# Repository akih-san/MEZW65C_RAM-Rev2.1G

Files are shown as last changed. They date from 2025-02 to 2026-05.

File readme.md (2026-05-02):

# MEZW65C_RAM-Rev2.1G

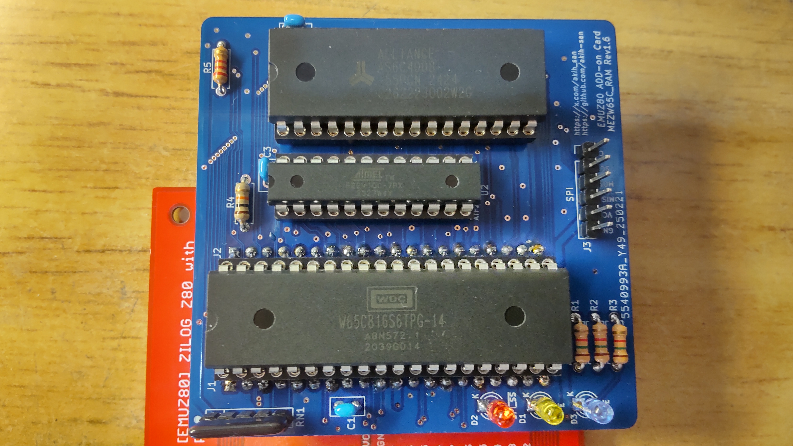
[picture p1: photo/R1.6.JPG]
<br>
（MEZW65C_RAM Rev1.6メザニンボード）
<br>

## MEZW65C_RAM-Rev2.1（PCB Rev1.3)からの改良点<br>
<br>
１．CPUの高速化<br>
２．CPLD(GAL)導入によるPCBの部品点数を削減<br>
３．ファームウェアによる6502、65816の自動判定<br>

#### １．CPUの高速化(6502:10MHz, 65816:8Mhz)
Rev2.1(PCB Rev1.3)は、6502(8MHz)、65816(6MHz)で動作しています。<br>
しかし、W65C02S6TPG-14とW65C816S6TPG-14を定格のは14MHzです。<br>
使用しているSRAM(AS6C4008-55PCN)のアクセスタイムは55nsですから、<br>
もう少し早く動かすことが出来るはずです。<br>
色々調べた結果、少し回路を修正すれば出来そうです。<br>
その為には、標準ロジックICを追加する必要がありますが、<br>
PCB Rev1.3には面積的にICを追加することは不可能な状況でした。<br>
<br>
今回、CPLDを導入し、部品点数を減らしたPCBを作成することで、<br>
6502で10MHz、65816では8MHzで動作することが出来るようになります。<br>
<br>
（65816について補足）<br>
65816は、クロックの半周期（CLKの立ち上がり）でメモリアドレス確定し、<br>
残りの半周期（CLKの立下り）でデータを確定する仕様です。<br>
またデータ確定時（CLKの立ち下がり）のsetup timeが最低10ns必要となります。<br>
このため、アクセスタイム55nsのSRAM(AS6C4008-55PCN)では、55ns+10ns=65nsが<br>
データ確定までに必要な時間となります。<br>
このため、動作クロックの論理値は、f=1/(65ns*2)となり、[約7.69MHz](photo/w65c816%20timing%20chart.png)となります。<br>
8MHzは実力で動作しているようなので、設定ファイル（MEZW16.CFG）には8MHzで動作するように<br>
設定してあります。<br>
メモリ、CPUの個体差で動作しない場合、クロックを7MHzに下げてください。<br>
<br>
<br>
＜余談＞<br>
14MHzで動かすには、もっと高速なSRAMが必要です。<br>
X(旧Twitter)の@DragonBallEZさんが、MH678127UHJ-12の高速SRAMを<br>
AS6C1008のピン配置に変換するアダプタ「Little Demon1 Rev0.3」を<br>

を作成しているので、 それを使って実験したところ、[14MHzで動作](photo/opening14MHz.png)することが<br>
確認出来ました。[ASCIIARTの結果](photo/asciiart.png)<br>
（MH678127UHJ-12は秋月電子通商での販売が終了しており、入手困難です）<br>

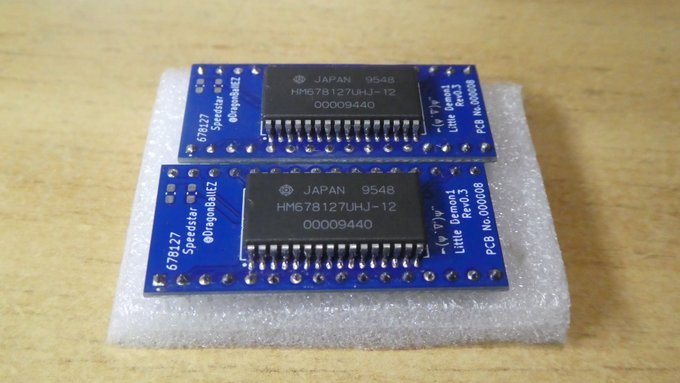
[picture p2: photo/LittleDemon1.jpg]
<br>
（Little Demon1 Rev0.3）
<br>

#### ２．CPLD(GAL)導入によるPCBの部品点数を削減
Glue logicは、CPLDを使えば複数の標準ロジックICを、規模にもよりますが<br>
１つにまとめることが可能です。<br>
PCB Rev1.3には３つの標準ロジックICがあります。追加のGlue logicと<br>
３つの標準ロジックICを、１つの22V10タイプのCPLDにまとめることが出来ました。<br>
CPLDは、私自信にとって初めての挑戦でしたが、うまくいきました。<br>

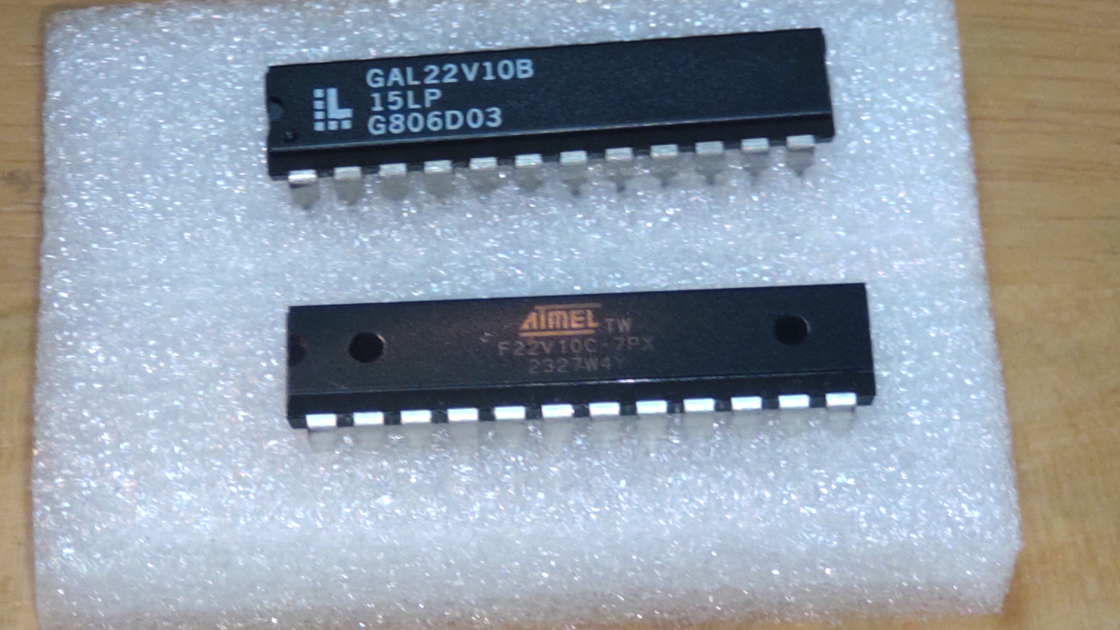
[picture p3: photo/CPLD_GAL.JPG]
<br>
（今回使用したCPLDとGAL）
<br>

#### ３．ファームウェアによる6502、65816の自動判定<br>
Rev2.1(PCB Rev1.3)は、切替スイッチを使って手動でCPUの種類を切り替えていました。<br>
Rev1.2G(PCB Rev1.6)では、ファームウェアによってCPUを自動判定します。<br>
その為、切り替えスイッチが無くなっています。<br>
<br>
CPLDの導入と、ファームウェアによるCPUの自動判定により、PCBの部品点数が削減されて<br>
スッキリとなりました。<br>
CPUの抜き差しをしやすいように、LEDの配置を変更しています。<br>
部品点数が減ったため、SRAMやPLDの抜き差しも楽になりました。<br>

# CPLDへのプログラミングと書き込み
CPLDの開発環境は、マイクロチップ社がPLD Design Resourcesとして[WinCUPL](https://www.microchip.com/en-us/products/fpgas-and-plds/spld-cplds/pld-design-resources)を提供しています。<br>
プログラミング自体は、慣れたテキストエディタを使えます。コンパイルとコード生成（jedファイル）<br>
をWinCUPLで行います。<br>
WinCUPLは少し古いソフトですが、Windows11でも動作しています。ただし、インストールすると<br>
既存の環境変数を書き換えてしまうので、既存の環境変数をバックアップしておく必要があります。<br>
そうしないと、既存のソフトウェアが立ち上がらなくなったりする不具合が発生するので、<br>
注意が必要です。<br>
CPLDのプログラミングについては[ここ](https://satoru8765.hatenablog.com/entry/2024/09/16/174243)が参考になると思います。<br>
<br>
 - CPLDへの書き込み<br>

   CPLDには、ROMライタを使用してMEZW65C_RAM.jedファイルを書込みます。<br>
   使用したのは、XGecu Programmer Model TL866Ⅱ PLUSです。<br>
   少し古いですが、問題なく書き込みが出来ました。XGecu Official Siteは[こちら](https://xgecu.myshopify.com/)<br>

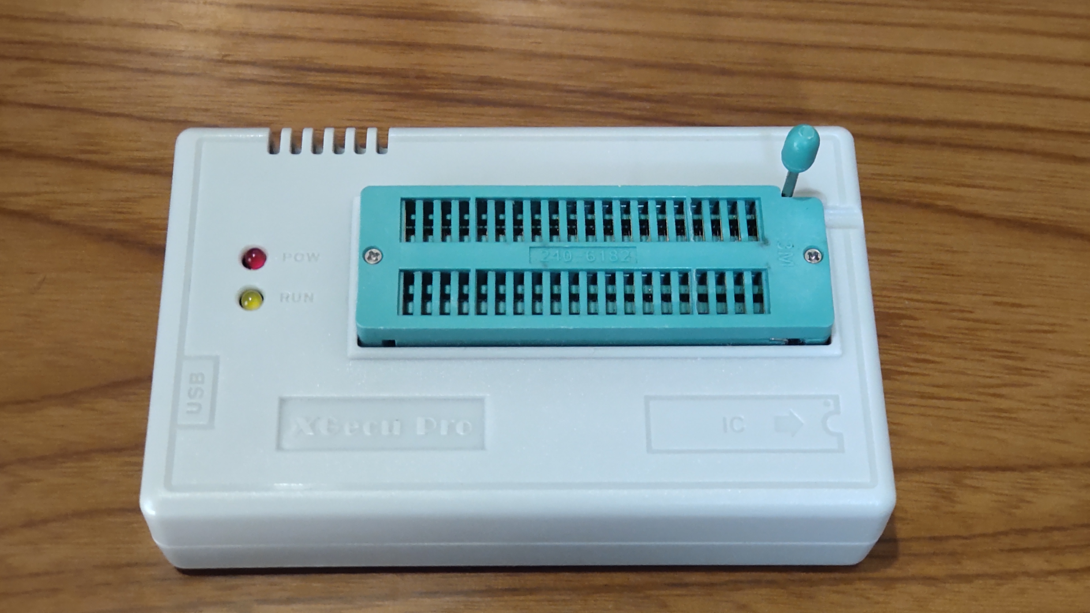
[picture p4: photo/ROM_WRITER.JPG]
   <br>
（今回使用したROMライタ）

# PIC18F47Q43/Q84/Q83への書き込み
PICへの書き込みツールを用いて、ヘキサファイルを書き込みます。<br>
<br>
- PIC18F47Q43 - R2.1GQ43.hex
- PIC18F47Q84 - R2.1GQ84.hex
- PIC18F47Q83 - R2.1GQ83.hex
<br>
＜注意点＞<br>
EMUZ80ボードから、メザニンボード（MEZW65C_RAM Rev2.1G）を外した状態で<br>
PICへの書き込みを行います。メザニンボードを装着しての書き込みは、失敗が<br>
多いです。<br>
もしくは、PICに書き込めるライターを使用します。<br>
<br>
- snap(マイクロチップ社の書き込みツール)<br>

  - [snap](https://www.microchip.com/en-us/development-tool/PG164100)

<br>
- PICkit3（または互換ツール）<br><br>
  PICkitminus書き込みソフトを用いて、書き込むことが出来ます。以下で入手できます。<br>

  - [PICkitminus](http://kair.us/projects/pickitminus/)
<br>

# μSDカードの作成
[MEZW65C_RAM Rev2.1のDISKSディレクトリの中身全部](https://github.com/akih-san/MEZW65C_RAM-Rev2.1/tree/main/DISKS)のファイルをμSDカードにコピーします。<br>
6502/65816を10MHzで動かすため、[コンフィグファイル](DISKS)を上書きします。<br>
<br>

# その他
詳細については、<br>
  - [MEZW65C_RAM Rev2.0](https://github.com/akih-san/MEZW65C_RAM-Rev2.0)<br>
  - [MEZW65C_RAM Rev2.1](https://github.com/akih-san/MEZW65C_RAM-Rev2.1)<br>
<br>
を参照してください。<br>

# 参考

＜EMUZ80＞<br>
EUMZ80はZ80CPUとPIC18F47Q43のDIP40ピンIC2つで構成されるシンプルなコンピュータです。<br>
（電脳伝説 - EMUZ80が完成）  <br>
https://vintagechips.wordpress.com/2022/03/05/emuz80_reference  <br>
<br>
＜SuperMEZ80＞<br>
SuperMEZ80は、EMUZ80にSRAMを追加しZ80をノーウェイトで動かすことができます。<br>
https://github.com/satoshiokue/SuperMEZ80<br>
<br>
＜＠hanyazouさんのソース＞<br>
https://github.com/hanyazou/SuperMEZ80/tree/mez80ram-cpm<br>
<br>
＜@electrelicさんのユニバーサルモニタ＞<br>
https://electrelic.com/electrelic/node/1317<br>

＜オレンジピコショップ＞  <br>
オレンジピコさんでEMUZ80、その他メザニンボードの購入できます。<br>
<br>
https://store.shopping.yahoo.co.jp/orangepicoshop/pico-a-051.html<br>
https://store.shopping.yahoo.co.jp/orangepicoshop/pico-a-061.html<br>
https://store.shopping.yahoo.co.jp/orangepicoshop/pico-a-062.html<br>
https://store.shopping.yahoo.co.jp/orangepicoshop/pico-a-079.html<br>
https://store.shopping.yahoo.co.jp/orangepicoshop/pico-a-087.html<br>
https://store.shopping.yahoo.co.jp/orangepicoshop/pico-a-089.html<br>

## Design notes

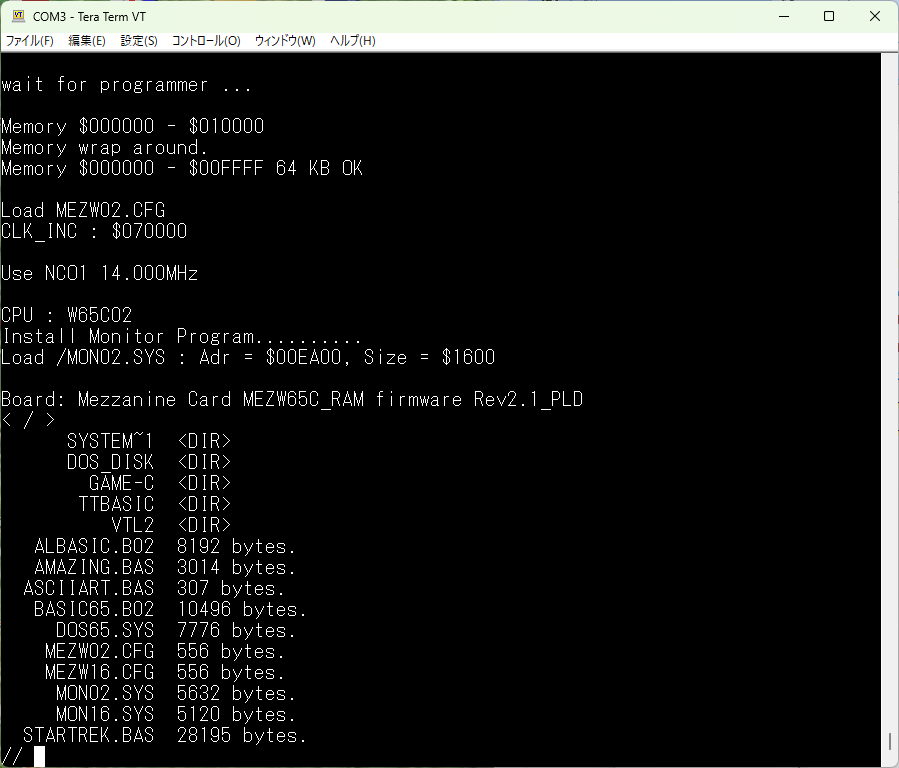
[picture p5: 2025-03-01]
photo/opening14MHz.png

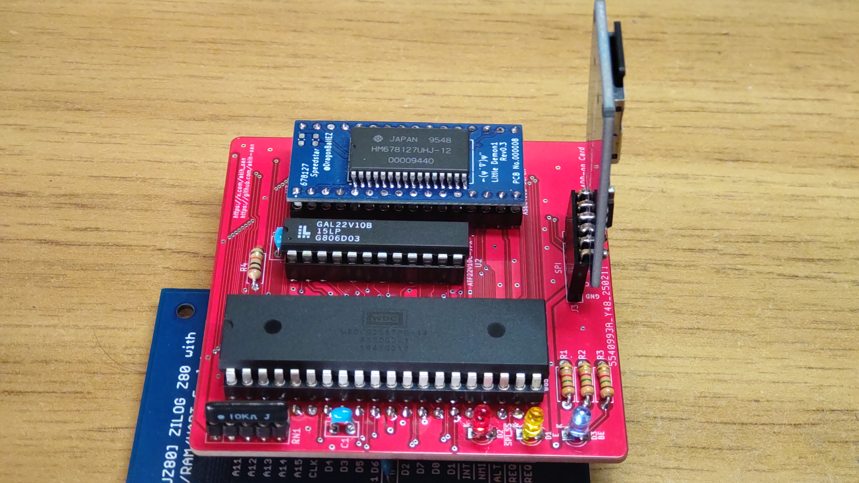
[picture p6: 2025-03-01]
photo/R1.5_14MHz.JPG

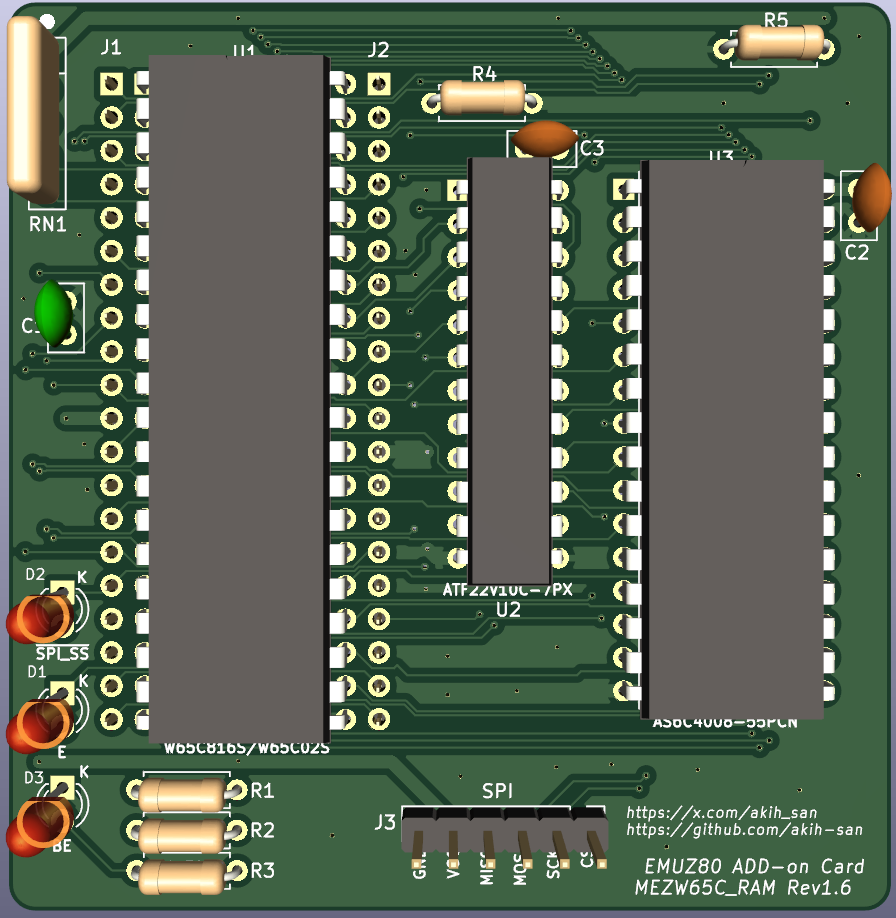
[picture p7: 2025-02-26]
photo/MEZ65C_RAM Rev1.6_1.png

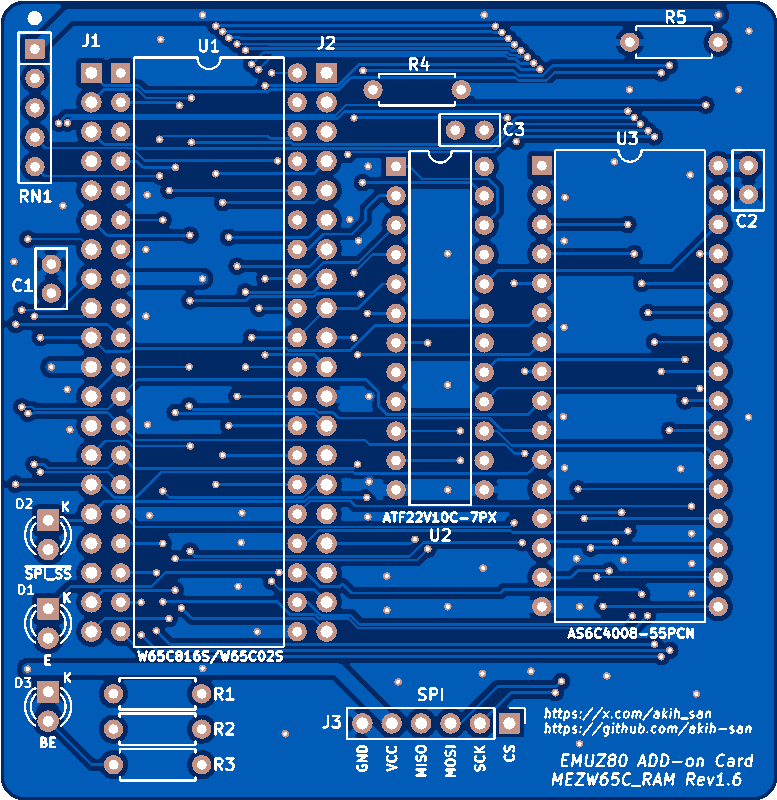
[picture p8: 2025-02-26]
photo/MEZ65C_RAM Rev1.6_2.png

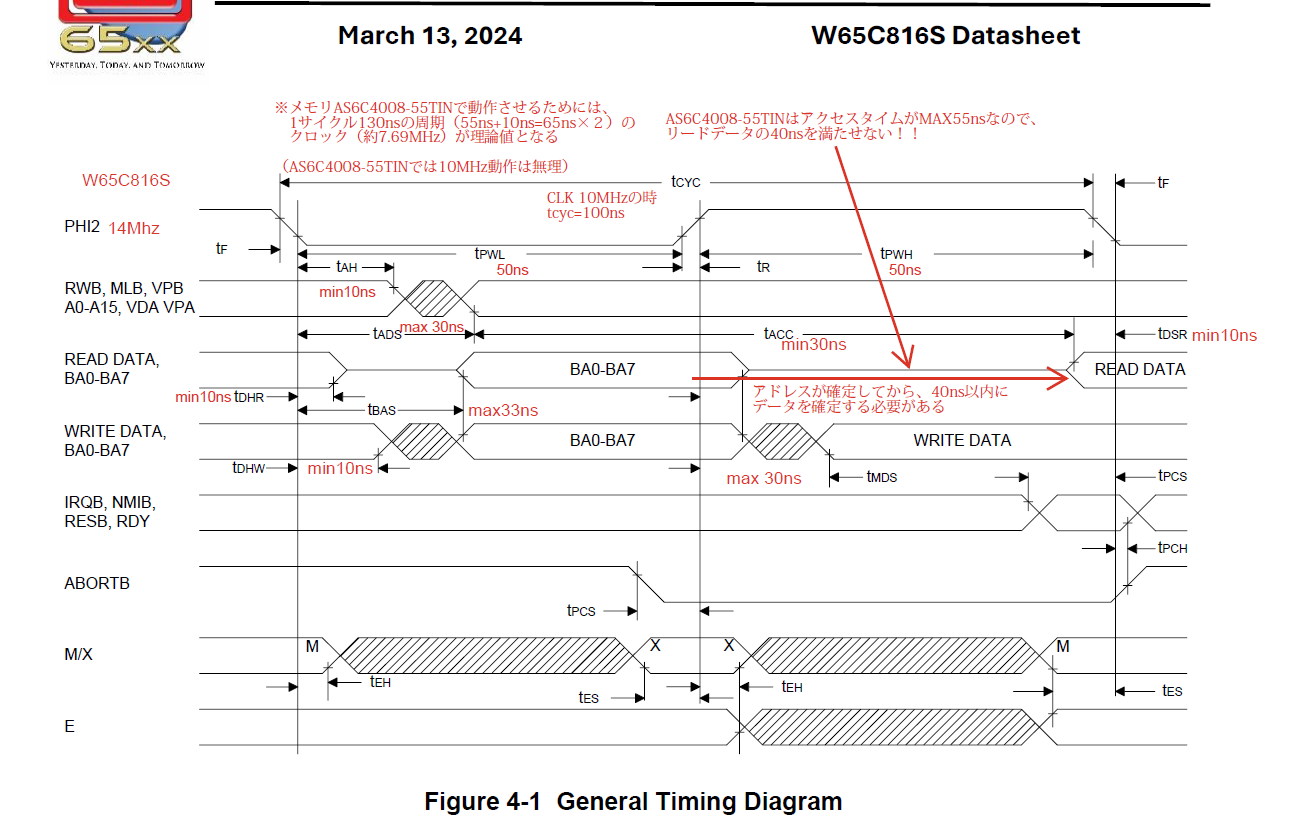
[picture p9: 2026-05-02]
photo/w65c816 timing chart.png

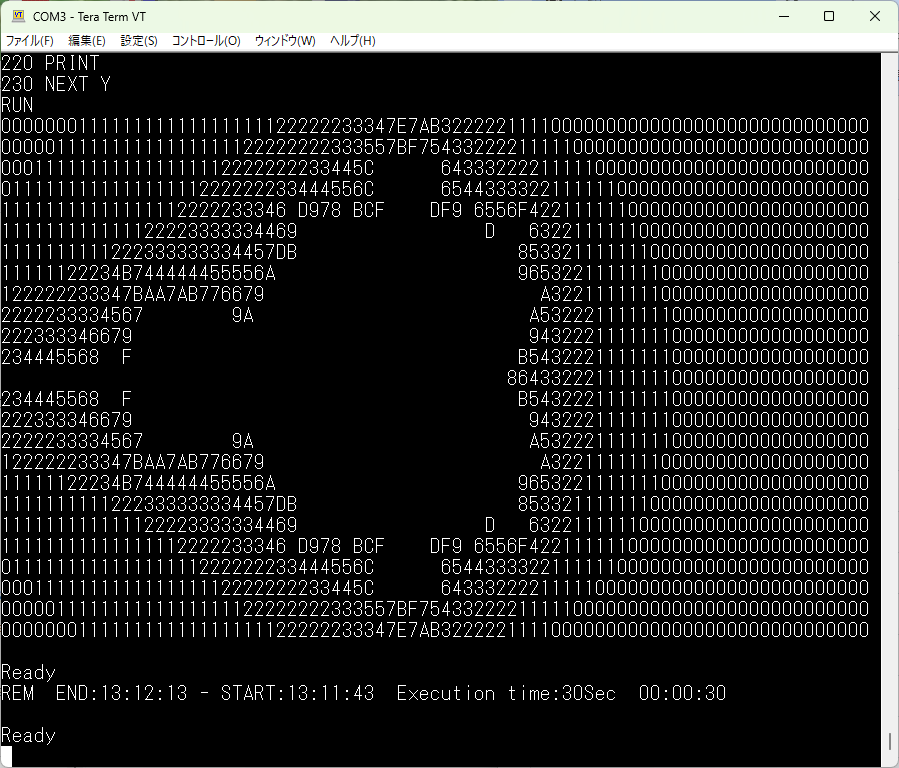
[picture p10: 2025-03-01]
photo/asciiart.png

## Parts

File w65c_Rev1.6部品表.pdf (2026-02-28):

＜w65c_Rev1.6 列 1 | | 列 2 | 列 3 | 列 4
No. | 部品番号 | 数 | 値、品番 | 名称

1

2 | D1,D2,D3 | 3 | LED | 発光ダイオード　順電圧 2 - 2.2V
3 | J1,J2 | 2 | 20ピンソケット | EMUZ80接続用2.54mmピッチ
4 | J3 | 1 | SPI | μSDカード用 1x06 2.54mmピッチピンヘッダ
5 | R1,R2,R3 | 3 | 1.5KΩ 1/4W | カーボン抵抗(炭素皮膜抵抗)
6 | R4 | 1 | 10KΩ 1/4W | カーボン抵抗(炭素皮膜抵抗)
7 | R5 | 1 | 2.2KΩ 1/4W | カーボン抵抗(炭素皮膜抵抗)
8 | RN1 | 1 | 4素子 10kΩ | 集合抵抗 4素子
9 | U1 | 1 | CPU | CPU W65C816S / W65C02 （DIP40）
10 | U2 | 1 | CPLD(GAL | ATF22V10C-7PXまたは、GAL22V10B-15LP
11 | U3 | 1 | AS6C4008-55PCN | 512kw×8bit SRAM（DIP32)
C1,C2,C3 | 3 | 0.1μF | 積層セラミックコンデンサー　D5.0mm W2.5mm P2.50mm

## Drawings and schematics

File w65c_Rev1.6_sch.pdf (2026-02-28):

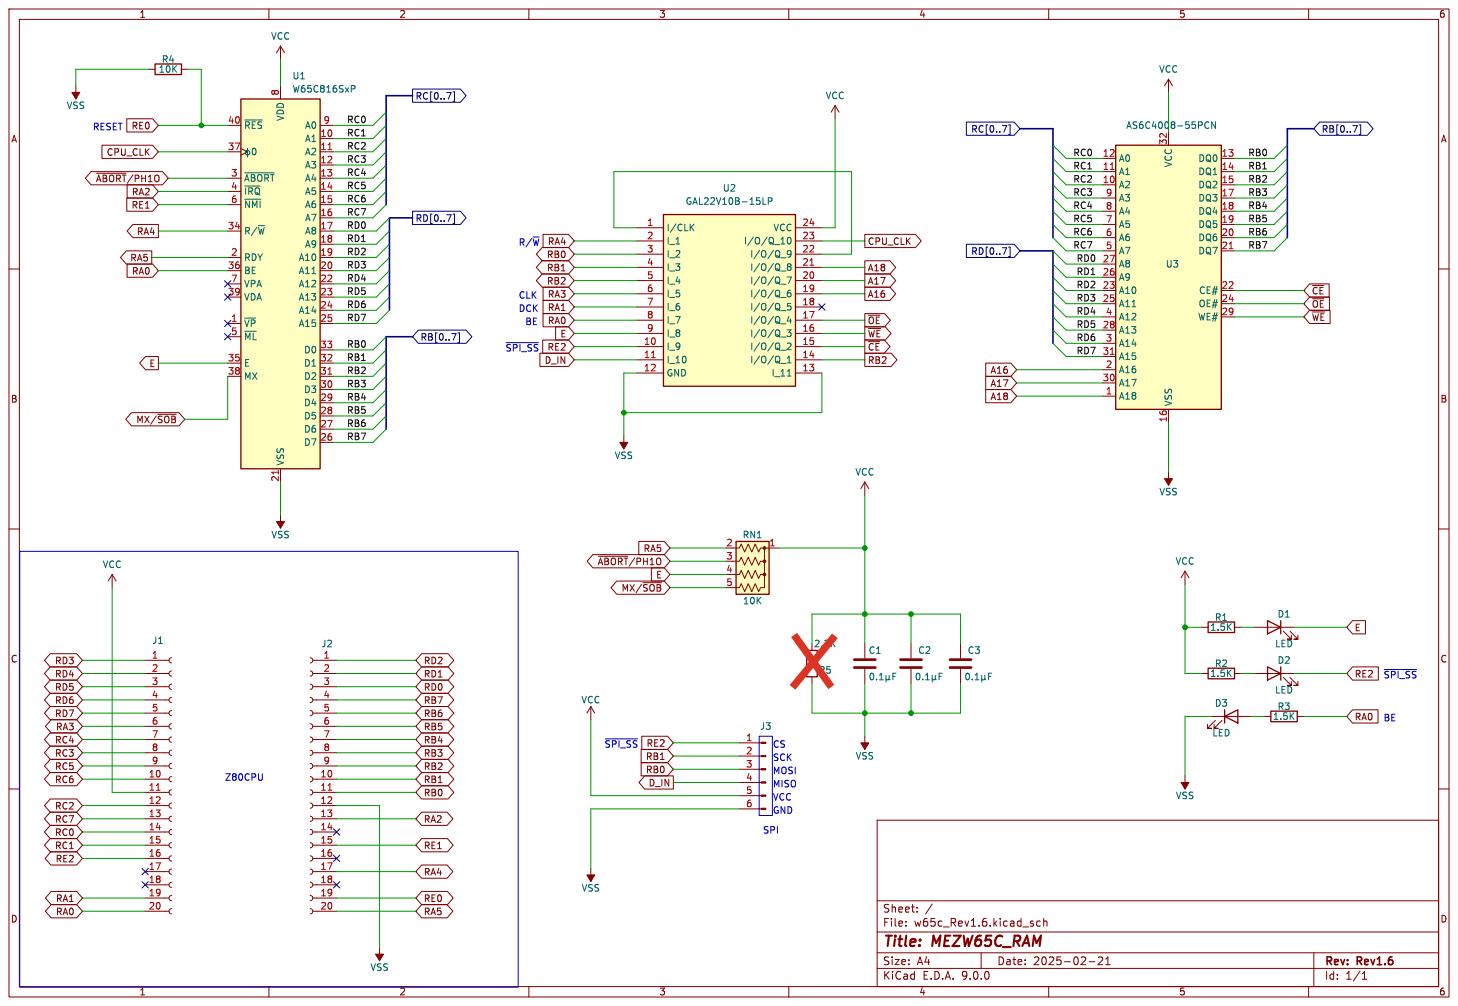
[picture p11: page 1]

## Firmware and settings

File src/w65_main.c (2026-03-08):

/*
 * Based on main.c by Tetsuya Suzuki 
 * and emuz80_z80ram.c by Satoshi Okue
 * PIC18F47Q43/PIC18F47Q83/PIC18F47Q84 ROM image uploader
 * and UART emulation firmware.
 * This single source file contains all code.
 *
 * Base source code of this firmware is maked by
 * @hanyazou (https://twitter.com/hanyazou) *
 *
 *  Target: MEZW65C02_RAM
 *  Written by Akihito Honda (Aki.h @akih_san)
 *  https://x.com/akih_san
 *  https://github.com/akih-san
 *
 *  Date. 2024.8.30
 */

#define INCLUDE_PIC_PRAGMA
#include <stdio.h>
#include <stdlib.h>
#include <string.h>
#include <ctype.h>

#include "../src/w65.h"
#include "../drivers/utils.h"

/* Previous function declaration */
static int disk_init(void);
static int load_program(uint8_t * );
static uint8_t del_space(char *);
static int load_config(void);
static int get_line(char *, int);

static FRESULT scan_files(void);
static FRESULT scan_files1(void);
static FRESULT change_directory(void);
static FRESULT load_file(void);
static FRESULT mon_prog(void);
static FRESULT wstart_prog(void);
static FRESULT restart_prog(void);
static FRESULT return_cpu(void);
static FRESULT print_reg(void);
static FRESULT print_com(void);
static FRESULT boot_file(void);
static FRESULT mem_dump(void);
static FRESULT drive_cpu(void);
static FRESULT see_file(void);
static FRESULT flash_apl(void);
static FRESULT open_dos65(void);
static FRESULT close_dos65(void);

static void set_arg(char *);
static int setup_monitor(void);
static int in_file(void);
static unsigned int str_inf(char *, uint8_t);

#define BS	0x08
#define CR	0x0d
#define BUF_SIZE TMP_BUF_SIZE * 2

#define INPUT_UART	0
#define INPUT_FILE	1

debug_t debug = {
    0,  // disk
    0,  // disk_read
    0,  // disk_write
    0,  // disk_verbose
    0,  // disk_mask
};

/* define structure type */
typedef struct {
	const TCHAR *conf;
	uint32_t *val;
} sys_param;

typedef struct {
	char *cmd_name;
	FRESULT (*func)(void);
} com_param;

static const char *mezID = "MEZW65C";
static char *board_name = "Mezzanine Card MEZW65C_RAM firmware Rev2.1_PLD";
static const TCHAR *conf02 = "MEZW02.CFG";
static const TCHAR *conf16 = "MEZW16.CFG";
static char *mon02 = "/MON02.SYS";
static char *mon16 = "/MON16.SYS";

static char *dosdir	= "DOS_DISK";
static char *dos65 = "/DOS65.SYS";

/* global values */
drive_t drives[NUM_DRIVES];

file_header fh;

uint8_t tmp_buf[2][TMP_BUF_SIZE];

int (*get_char[2])(void) = {
	u_getch,
	in_file
};

unsigned int (*strin_func[2])(char *, uint8_t) = {
	get_str,
	str_inf
};

uint8_t cin_no;			// 0 : INPUT_UART 1 : INPUT_FILE

uint32_t clk_fs;
uint32_t bioreq_ubuffadr;
uint32_t bioreq_cbuffadr;

// CPU flg 0:W65C02 1:W65C816
uint8_t	cpu_flg;
uint8_t	wup_flg;
uint8_t	nmi_sig;

/* local values */
static uint16_t frd_ptr;		// read pointer : cin_file[frd_ptr]
static uint16_t fin_cnt;
static uint16_t fin_size;
static char fin_name[13];		// redirect file name

static FATFS fs;
static FILINFO fileinfo;
static FIL rom_fl;
static FIL in_fl;
static FIL files[NUM_DRIVES];

static uint32_t raw_addr;
static uint16_t file_size;
static uint8_t load_flg;

#define line_size 81
static char line_buf[line_size];

#define arg_num 5
static char *arg[arg_num];

#define num_param 2
#define num_com 15
//#define num_com 14
static sys_param t_conf[num_param] = {
	{"CLK_INC", &clk_fs},
	{"REQ_HDR", &bioreq_ubuffadr}
};

static com_param cmd[num_com+1] = {
	{"LS", scan_files},
	{"DIR",scan_files1},
	{"CD",change_directory},
	{"LOAD",load_file},
	{"CSTART",restart_prog},
	{"WSTART",wstart_prog},
	{"RETI",return_cpu},
	{"REG",print_reg},
	{"MONITOR", mon_prog},
	{"MDUMP",mem_dump},
	{"SHOW",see_file},
	{"FLASH",flash_apl},
	{"DOS65",open_dos65},
	{"HELP",print_com},
	{"?",print_com},
	{"",boot_file}
};

#define BINV_SIZE 7
typedef struct {
//---transfer data to monitor mezID area---
	uint8_t		sw;		// +0 0: user program none 
						//    1: user program exist
	uint16_t	addr;	// +1 (copied caddr or waddr)
	uint8_t		pbnk;	// +3 PBR
	uint8_t		dbnk;	// +4 DBR
	uint16_t	dp;		// +5 DPR
//----------------------------------------
	uint16_t	caddr;	// user program cold start
	uint16_t	waddr;	// user program warm start
	uint8_t		sw_816;	// 0 : W65C02, 1: W65C816 native mode, 2:works in both modes
	TCHAR	fname[30];	// BIOS program faile name
} bios_inv;

static bios_inv binv;
static uint8_t mon;

// main routine

void main(void)
{
	int c, fr;
	char *buf, *res;
	FRESULT rs;
	
	cin_no	= INPUT_UART;	// input console (UART)
	wup_flg = 0;	// clear wakeup flag for NMI
	nmi_sig = 0;
	fh.nmi_sw = 0;
	raw_addr = 0;
	load_flg = 0;
	binv.sw = 0;
	cpu_flg = 0;

	uart_init();
	wait_for_programmer();

	port_init();
	setup_ivt();

	setup_sd();
	if (disk_init() < 0) while (1);

	clk_init();		// initial CLK = 2MHz
	clc_init();

	cpu_flg = reset_cpu();

	// memory test
	mem_init();

	if( load_config() < 0) while (1);
	printf("\r\nUse NCO1 %2.3fMHz\r\n\n",(double)clk_fs * 30.5175781 / 1000000);
	
	if (!cpu_flg) printf("CPU : W65C02\r\n");
	else printf("CPU : W65C816\r\n");

	reset_clk();
	setup_tomer0();		//Start IRQ timer
	enable_interrupt();

	if ( setup_monitor() ) {
		printf("System stop!!");
		while(1) {}
	}
		
	printf("\r\nBoard: %s\n\r", board_name);

	/* set root directory */
	f_getcwd(&line_buf[0], line_size);
	arg[0] = "";
	scan_files();
	
	for(;;) {
		buf = (char *)&tmp_buf[0][0];
		f_getcwd(buf, line_size);
		printf("%s/ ", buf);									/* pirnt prompt */
		for(c = 0; c < arg_num; c++) arg[c] = 0;

		if (!get_line(&line_buf[0], line_size)) continue;		/* console input */
		/* search command */
		for( c=0;  c < num_com; c++ ) {
			if ((res = strstr(&line_buf[0], cmd[c].cmd_name ))) {
				buf = (char *)(res+strlen(cmd[c].cmd_name));		/* buf = next point */
				set_arg(buf);
				break;
			}
		}
		// do command operation
		if ( c == num_com ) set_arg(&line_buf[0]);
		rs = (*cmd[c].func)();								/* call cmd function */

		if( rs == (FRESULT)-2 ) printf("\r\nAssert NMI interrupt.\r\n");
		else if ( rs != FR_OK ) printf("Invalid( command | file | directory )\r\n");
	}
	
}

//
// setup monitor at starting MESW65C_RAM
//
static int setup_monitor(void) {

	int	rs;
	uint8_t dat;
	
	printf("Install Monitor Program..........\r\n");

	if (cpu_flg) {
		arg[0] = mon16;
		mon = 1;
	}
	else {
		arg[0] = mon02;
		mon = 0;
	}
	rs = load_program((uint8_t *)arg[0]);
	if ( rs ) return rs;

	//
	// Start CPU
	//
	start_cpu();
	drive_cpu();
	return 0;
}

//
// load program from SD card
//
static int load_program(uint8_t *fname) {
	
	FRESULT	fr;
	void	*rdbuf;
	UINT	btr, br;
	uint16_t	cnt;
	uint32_t	adr, adr0;
	file_header *header;
	
	rdbuf = (void *)&tmp_buf[0][0];		// program load work area(512byte)
	header = (file_header *)&tmp_buf[0][0];

	fr = f_open(&rom_fl, (TCHAR *)fname, FA_READ);
	if ( fr != FR_OK ) {
		printf("File Open Error.\r\n");
		return((int)fr);
	}
	adr = 0;
	cnt = file_size = (uint16_t)f_size(&rom_fl);				// get file size
	btr = BUF_SIZE;								// default 512byte
	while( cnt ) {
		fr = f_read(&rom_fl, rdbuf, btr, &br);
		if (fr == FR_OK) {
			if ( !adr ) {
				if ( raw_addr ) {
					adr = adr0 = raw_addr;
				}
				else {
					if (!strstr((const char *)header->mezID, mezID)) {
						printf("Invalid MEZW65C file.\r\n");
						fr = FR_INVALID_OBJECT;
						break;
					}
					if (header->sw_816==1 && !cpu_flg) {
						printf("Work on only W65C816..\r\n");
						fr = FR_INVALID_OBJECT;
						break;
					}
					adr = adr0 = header->load_p;
					if (!load_flg) {
						if ( header->bios_sw == 1 ) {	// file is user program
							binv.sw = header->bios_sw;
							binv.caddr = header->cstart_addr;
							binv.waddr = header->wstart_addr;
							binv.dp = header->direct_page;			//direct page
							binv.pbnk = header->op1;				//program bank
							binv.dbnk = header->op2;				//data bank
							binv.sw_816 = header->sw_816;
							sprintf((char *)binv.fname, "%s", fname);
						}
						else {
							// copy file header */
							fh.bios_sw = header->bios_sw;
							fh.load_p = header->load_p;
							fh.sw_816 = header->sw_816;
							fh.cstart_addr = header->cstart_addr;
							fh.wstart_addr = header->wstart_addr;
							fh.picif_p = header->picif_p;
							fh.irq_sw = header->irq_sw;
							fh.reg_tblp = header->reg_tblp;
							fh.reg_tsize = header->reg_tsize;
							fh.nmi_sw = header->nmi_sw;
							/* PIC common memory address */
							bioreq_ubuffadr = fh.picif_p;
							bioreq_cbuffadr = bioreq_ubuffadr + 2;
							if ( !fh.bios_sw ) binv.sw = 0;		// standalone(clear bios call flag)
						}
					}
				}
			}
			write_sram(adr, (uint8_t *)rdbuf, (unsigned int)br);
			adr += (uint32_t)br;
			cnt -= (uint16_t)br;
			if (btr > (UINT)cnt) btr = (UINT)cnt;
		}
		else break;
	}
	if (fr == FR_OK) {
		printf("Load %s : Adr = $%06lX, Size = $%04X\r\n", fname, adr0, file_size);
	}
	else {
		if (fr != FR_INVALID_OBJECT) printf("File Load Error.\r\n");
	}
	f_close(&rom_fl);
	return((int)fr);
}

//
// mount SD card
//
static int disk_init(void)
{
    if (f_mount(&fs, "0://", 1) != FR_OK) {
        printf("Failed to mount SD Card.\n\r");
        return -2;
    }

    return 0;
}

static uint8_t del_space(char *bytes) {
	uint8_t pos = 0;
	uint8_t i = 0;
	char c;
	
	while( (c = bytes[i++]) ) {
		if (c == '\r' || c == '\n' || c == ' ') {
			continue;
		}
		bytes[pos++] = c;
	}
	bytes[pos] = c;		// save NULL code
	return pos;
}

static int load_config(void)
{
	FRESULT	fr;
	char *buf, *a;
	const TCHAR *conf;
	uint16_t cnt, size;
	uint16_t adr;
	int i;
	TCHAR *str;
	
	str = (TCHAR *)&tmp_buf[0][0];
	conf = ( cpu_flg ) ? conf16 : conf02;
	
	printf("\r\nLoad %s\r\n",(const char *)conf);
	
	fr = f_open(&rom_fl, conf, FA_READ);
	if ( fr != FR_OK ) {
		printf("%s not found..\r\n", conf);
		return -1;
	}

	while ( f_gets(str, 80, &rom_fl) ) {	// max 80 characters

		// delete space
		del_space(str);

		if (str[0] == ';' || str[0] == 0 ) continue;

		// search keywoard
		for( i=0; i<num_param; i++ ) {
			if ( !strstr(str, t_conf[i].conf )) continue;
			if(str[strlen(t_conf[i].conf)] != '=') continue;

			// get value
			buf = &str[strlen(t_conf[i].conf)+1];
			if (!(*(t_conf[i].val) = (uint32_t)strtol((const char *)buf, &a, 0))) {
				printf("%s : invalid value!!\r\n",t_conf[i].conf);
				f_close( &rom_fl );
				return -1;
			}
			printf("%s : $%06lx\r\n", (const char *)t_conf[i].conf, *(t_conf[i].val));
		}
	}

	if (!f_eof(&rom_fl)) {
		printf("File read error!\r\n");
		f_close( &rom_fl );
		return -1;
	}
	f_close( &rom_fl );
	return 0;
}

static int get_line(char *s, int length) {
	char n;
	int c;
	
	for (c=0;;) {
		n = (char)getch();
		if ( n == BS ) {
			if ( c > 0) {
				putch(BS);
				putch(' ');
				putch(BS);
				c--;
				s--;
			}
			continue;
		}
		if ( n == 0x0d || n == 0x0a ) {
			*s = 0x00;
			printf("\r\n");
			return c;
		}
		if ( c <= line_size-1 ) {
			putch(n);
			if ( n >='a' && n <='z' ) n -= 0x20;		// lower to upper
			*s++ = n;
			c++;
		}
	}
	return c;
}

static FRESULT scan_files(void) {	/* *path = directory name "/": root */
	FRESULT res;
	FILINFO fno;
	DIR *dir;
	char *fn;
	TCHAR *p;

	p = (char *)&tmp_buf[0][0];
	res = f_getcwd( p, line_size);

	dir = (DIR *)&tmp_buf[1][0];
	res = f_opendir(dir, arg[0]);
	if (res == FR_OK) {		// directory
		if ( *arg[0] == '\0' ) printf("< %s >\r\n", p );
		else if ( !(*(char *)(p+1)) ) printf("< /%s >\r\n", arg[0] );
		else printf("< %s/%s >\r\n", p, arg[0] );

		for (;;) {
			res = f_readdir(dir, &fno);
			if (res != FR_OK || fno.fname[0] == 0) break;
			if (fno.fname[0] == '.') continue;				/* ignore '.'  */
			fn = fno.fname;
			if (fno.fattrib & AM_DIR) {					/* Directory */
				printf("  %12s\t<DIR>\r\n", fno.fname);
			}
			else {									/* file */
				printf("  %12s\t%ld bytes.\r\n", fn, fno.fsize);
			}
		}
		f_closedir(dir);
	}
	else {
		if (res == FR_NO_PATH) { // check file
			res = f_open(&rom_fl, (const TCHAR *)arg[0], FA_READ);
			if ( res == FR_OK ) {
				printf("  %12s\t%ld bytes.\r\n", arg[0], f_size(&rom_fl));
				f_close( &rom_fl );
			}
		}
	}
	return res;
}

static FRESULT scan_files1(void) {	/* *path = directory name "/": root */
	FRESULT res;
	FILINFO fno;
	DIR *dir;
	uint8_t	fcnt;
	
	char *fn, *p, *path;

	path = arg[0];
	dir = (DIR *)&tmp_buf[1][0];
	fcnt = 0;
	
	res = f_opendir(dir, path);
	if (res == FR_OK) {		// directory
		p = (char *)&tmp_buf[0][0];
		f_getcwd( p, line_size);
		
		if ( *path == '\0' ) printf("< %s >\r\n", p );
		else if ( !(*(char *)(p+1)) ) printf("< /%s >\r\n", path );
		else printf("< %s/%s >\r\n", p, path );

		for (;;) {
			res = f_readdir(dir, &fno);
			if (res != FR_OK || fno.fname[0] == 0) {
				if ( fcnt ) {
					printf("\r\n");
					break;
				}
			}
			if (fno.fname[0] == '.') continue;				/* ignore '.'  */
			fn = fno.fname;
			if (fno.fattrib & AM_DIR) {					/* Directory */
				printf("[%12s] ", fn);
			}
			else {									/* file */
				printf(" %12s  ", fn);
			}
			fcnt += 1;
			if (fcnt == 5 ) {
				printf("\r\n");
				fcnt = 0;
			}
		}
		f_closedir(dir);
	}
	else {
		if (res == FR_NO_PATH) { // check file
			res = f_open(&rom_fl, (const TCHAR *)path, FA_READ);
			if ( res == FR_OK ) {
				printf("  %12s\t%ld bytes.\r\n", path, f_size(&rom_fl));
				f_close( &rom_fl );
			}
		}
	}
	return res;
}

static void set_arg(char *buf) {

	int i;
	
	i=0;
	while( i < arg_num ) {
		while( *buf == ' ' ) buf++;
		arg[i] = buf;
		if ( !*buf ) break;
		while( *buf && *buf != ' ' ) buf++;
		if ( !*buf ) break;
		if ( *buf == ' ' ) *buf++ = 0;
		i++;
	}
}

static FRESULT drive_cpu(void) { 

	FRESULT rs;

	nmi_sig = 0;
	if( !fh.irq_sw ) {
		timer_off();
		board_event_loop1();
	}
	else {
		timer_on();
		board_event_loop();
	}

	// wup_flg = 0xFF : NMI, wup_flg = 1 : sleep( or terminate )
	rs = (FRESULT)(wup_flg - 1);		// get wakeup reason -2:NMI 
	wup_flg = 0;						// clear wakeup flag for NMI

	return rs;
}


static void prt_reload(void) { 
	printf("Reload monitor %s\r\n", arg[0]);
}

static FRESULT boot_file(void) { 

	FRESULT rs;
	uint8_t flag, m;
	UINT cnt;
	
	if ( strstr((const char *)arg[0], mon02+1) ) m = 0;
	else if ( strstr((const char *)arg[0], mon16+1) ) m = 1;
	else m = 2;
	if ( m != 2) {
		mon = m;
		prt_reload();
		binv.sw = 0;	//clear user program
		rs = (FRESULT)load_program((uint8_t *)arg[0]);
		if ( rs ) return 0;

		start_cpu();
		rs = drive_cpu();
		return rs;
	}
	
	// check mark '<' for FILE INPUT modde
	if ( *arg[1] == '<' ) {
		sprintf(&fin_name[0], "%s", arg[2]);
		fin_cnt = 0xffff;	// set open flag
		cin_no = INPUT_FILE;								// change console input UART to FILE
	}

	//check DOS65.SYS
	if ( strstr((const char *)arg[0], dos65+1) ) {
		rs = open_dos65();
		return rs;
	}
	
	flag = 0;
	printf("Flie(%s) loading...\r\n", arg[0]);
	
	rs = (FRESULT)load_program((uint8_t *)arg[0]);
	if ( rs ) return 0;

	if ( binv.sw ) {	// user program
		if ( cpu_flg ) {	// 65816
			if ( mon ) {	//mon16
				if ( !binv.sw_816 ) {
					arg[0] = mon02;
					mon = 0;
					flag = 1;
					printf("Reload %s for Emulation Mode...\r\n", arg[0]);
				}
			}
			else {	// mon02
				if ( binv.sw_816 ) {
					arg[0] = mon16;
					mon = 1;
					flag = 1;
					printf("Reload %s for Native Mode...\r\n", arg[0]);
				}
			}
			if ( flag ) {	// reroad monitor
				rs = (FRESULT)load_program((uint8_t *)arg[0]);
				if ( rs ) return 0;
			}
		}
		binv.addr = binv.caddr;
		write_sram( fh.load_p+mezID_off, (uint8_t *)&binv, BINV_SIZE );		// address of monitor's mezID
	}

	write_sram(0xFFFC, (uint8_t *)&fh.cstart_addr, 2);
	start_cpu();	//set monitor cold start
	rs = drive_cpu();
	if ( !rs ) {
		if ( !fh.bios_sw ) {	// if standalone prpgram is terminated, then need reload monitor
			if (cpu_flg) {
				arg[0] = mon16;
				mon = 1;
			}
			else {
				arg[0] = mon02;
				mon = 0;
			}
			prt_reload();
			rs = (FRESULT)load_program((uint8_t *)arg[0]);
			if ( rs ) return 0;
			start_cpu();
			rs = drive_cpu();
		}
		binv.sw = 0;	// terminate bios_call program
	}
	return rs;
}

static FRESULT return_cpu(void) { 
	
	FRESULT rs;

	continue_action();
	rs = drive_cpu();
	return rs;
}

static FRESULT change_directory(void) { return(f_chdir( arg[0] )); } 

static FRESULT print_reg(void) { 
	reg816 *reg_816;
	reg02 *reg_02;

	read_sram((uint32_t)fh.reg_tblp, &tmp_buf[0][0], (unsigned int)fh.reg_tsize);

	if (fh.sw_816) {	/* 65816 */
		reg_816 = (reg816 *)&tmp_buf[0][0];
		printf("A=$%04X X=$%04X Y=$%04X SP=$%04X PC=$%04X PSR=$%02X\r\n",
				reg_816->REGA, reg_816->REGX,reg_816->REGY,reg_816->REGSP,reg_816->REGPC,reg_816->REGPSR);
		printf("PBR=$%02X DBR=$%02X DPR=$%04X\r\n",reg_816->REGPB, reg_816->REGDB, reg_816->REGDP);
	}
	else {
		reg_02 = (reg02 *)&tmp_buf[0][0];
		printf("A=$%02X X=$%02X Y=$%02X SP=$01%02X PC=$%04X PSR=$%02X\r\n",
				reg_02->REGA, reg_02->REGX,reg_02->REGY,reg_02->REGSP,reg_02->REGPC,reg_02->REGPSR);
	}
	return FR_OK;
}

static FRESULT print_com(void) { 
	
	printf("\r\n<< MEZW65C_RAM Firmware Built-in command >>\r\n");
	printf("  DOS65  (Key CTL+T : terminate DOS65)\r\n");
	printf("  LS | DIR [file name | directory name\r\n");
	printf("  CD [directory name]\n\r");
	printf("  LOAD [L=load address(Hex)] file name\r\n");
	printf("  MDUMP address(Hex)\r\n");
	printf("  MONITOR [W]\r\n");
	printf("  CSTART\r\n");
	printf("  WSTART\r\n");
	printf("  RETI\r\n");
	printf("  REG\r\n");
	printf("  SHOW file name\r\n");
	printf("  FLASH\r\n");
	printf("  HELP | ?\r\n");
	return FR_OK;
}
static FRESULT load_file(void) {
	char *p;
	
	load_flg = 1;
	if ((p = strstr(arg[0], "L=" ))) {
		raw_addr = get_hex((char *)(p+2));
		load_program((uint8_t *)arg[1]);
	}
	else {
		raw_addr = 0;
		load_program((uint8_t *)arg[0]);
	}
	load_flg = 0;
	raw_addr = 0;
	return FR_OK;
}

static FRESULT wstart_prog(void) {
	FRESULT rs;

	rs = FR_NO_FILE;
	if ( binv.sw == 1) {
		binv.addr = binv.waddr;
		write_sram( fh.load_p+mezID_off, (uint8_t *)&binv, BINV_SIZE );		// address of monitor's mezID
		
		write_sram(0xFFFC, (uint8_t *)&fh.cstart_addr, 2);
		start_cpu();
		rs = drive_cpu();
	}
	return rs;
}

static FRESULT restart_prog(void) {
	FRESULT rs;

	rs = FR_NO_FILE;
	if ( binv.sw ==1 ) {
		binv.addr = binv.caddr;
		write_sram( fh.load_p+mezID_off, (uint8_t *)&binv, BINV_SIZE );		// address of monitor's mezID

		write_sram(0xFFFC, (uint8_t *)&fh.cstart_addr, 2);
		start_cpu();
		rs = drive_cpu();
	}
	return rs;
}

static FRESULT mon_prog(void) {
	FRESULT rs;
	char *p;
	uint8_t	sw;
	
	rs = FR_OK;

	sw = 0;					// monitor wakeup signal
	write_sram( fh.load_p+mezID_off, &sw, 1 );			// address of  fh.mezID

	if ((p = strstr(arg[0], "W" ))) write_sram(0xFFFC, (uint8_t *)&fh.wstart_addr, 2);
	else write_sram(0xFFFC, (uint8_t *)&fh.cstart_addr, 2);

	start_cpu();
	rs = drive_cpu();
	printf("\r\n");
	return rs;
}

static FRESULT mem_dump(void) {

	uint32_t addr;
	char *p;
	
	p = arg[0];
	addr = get_hex( p );

	read_sram(addr, (uint8_t *)&tmp_buf[0][0], 128);		//128 bytes read memory
	util_addrdump("Mem ", addr, (const void *)&tmp_buf[0][0], 128);
	return FR_OK;
}

static FRESULT see_file(void) {
	
	FRESULT	fr;
	void	*rdbuf;
	UINT	br;
	file_header *header;

	rdbuf = (void *)&tmp_buf[0][0];		// program load work area(512byte)
	header = (file_header *)&tmp_buf[0][0];

	fr = f_open(&rom_fl, (TCHAR *)arg[0], FA_READ);
	if ( fr != FR_OK ) {
		printf("\r\nFile Open Error.\r\n");
		return 0;
	}

	file_size = (uint16_t)f_size(&rom_fl);		// get file size
	fr = f_read(&rom_fl, rdbuf, BUF_SIZE, &br);
	if (fr == FR_OK) {

		printf("\r\n%s : Size = $%04X bytes.\r\n", arg[0], file_size);
		if (!strstr((const char *)header->mezID, mezID)) {	// not MEZW65C_RAM format
			printf("Not MEZW65C_RAM format file.\r\n");
		}
		else {
			printf("FIle load address : $%06lX\r\n", (unsigned long)header->load_p );
			printf("File Type : ");
			switch (header->bios_sw) {
				case 0:		// standalone program
				case 2:		// MONITOR program
					if ( !header->bios_sw ) printf("Stand-alone\n\r");
					else printf("MONITOR\n\r");
					printf("Operational Mode : ");
					if (!header->sw_816) printf("W65C02 (Emulation Mode)\n\r");
					else printf("W65C816 Native mode\n\r");
					printf("CSTART : $%04X\r\n",header->cstart_addr);
					printf("WSTART : $%04X\r\n",header->wstart_addr);
					if (header->sw_816 == 1) printf("DPR : $%04X PBR : $00 DBR : $00\r\n",header->direct_page);
					printf("PIC I/F Shared memory : $%06lX\r\n",(unsigned long)header->picif_p);
					if ( header->bios_sw == 2 ) {
						if( header->irq_sw ) printf("IRQ : Support, ");
						else printf("IRQ : No support, ");
						if( header->nmi_sw ) printf("MNI : Support\r\n");
						else printf("MNI : No support\r\n");
					}
					break;
				case 1:		// user program
					printf("User Program.\n\r");
					printf("Operational Mode : ");
					switch (header->sw_816) {
						case 0:
							printf("W65C02 (Emulation Mode)\n\r");
							break;
						case 1:
							printf("W65C816 Native mode\n\r");
							break;
						case 2:
							printf("Both W65C02 and W65C816\n\r");
					}
					printf("CSTART : $%04X\r\n",header->cstart_addr);
					printf("WSTART : $%04X\r\n",header->wstart_addr);
					if (header->sw_816) printf("DPR : $%04X PBR : $%02X DBR : $%02X\r\n",header->direct_page, header->op1, header->op2);
			}
		}
	}
	printf("\r\n");
	f_close(&rom_fl);
	return 0;
}

static FRESULT flash_apl(void) {
	if ( binv.sw ) {
		printf("Terminate %s\r\n",binv.fname);
		binv.sw = 0;
		// close disk images if DOS65 was suspended by NMI
		close_dos65();
	}
	else printf("No Program to terminate.\r\n");

	return FR_OK;
}

static int in_file(void) {

	uint8_t	chr, *buf;

	if ( fin_cnt == 0xffff ) { // init : open file
		// open input file & set console input from file
		if ( f_open(&in_fl, &fin_name[0], FA_READ) ) {
			printf("File Open Error. %s\r\n", &fin_name[0]);
			cin_no = INPUT_UART;						// change console input to UART
			return 0;
		}

		buf = &tmp_buf[0][0];
		fin_cnt=0;
		frd_ptr = 0;
		fin_size = (uint16_t)f_size(&in_fl);				// get file size
	}
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

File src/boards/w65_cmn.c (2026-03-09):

/*
 *  This source is for PIC18F47Q43 UART, I2C, SPI and TIMER0
 *
 * Base source code is maked by @hanyazou
 *  https://twitter.com/hanyazou
 *
 * Redesigned by Akihito Honda(Aki.h @akih_san)
 *  https://twitter.com/akih_san
 *  https://github.com/akih-san
 *
 *  Target: MEZW65C02_RAM
 *  Date. 2024.6.21
*/

#define BOARD_DEPENDENT_SOURCE

#include "../w65.h"

// console input buffers
//#define U3B_SIZE 128
unsigned char rx_buf[U3B_SIZE];	//UART Rx ring buffer
unsigned int rx_wp, rx_rp, rx_cnt;

#define rom_org	0xffe7
#define cpu_type 0xfff9

const unsigned char rom[] = {
	0x18,           //    clc              ; set native mode
	0xFB,           //    xce              ; if cpu=W65C02 then xce = nop operation
	0xA9,0x00,      //    lda  #$00
	0xA2,0xFF,      //    ldx  #$ff
	0x9A,           //    txs              ; set SP (W65C02 OPECODE)
	0x1B,           //    tas              ; set SP (W65C816 OPECODE)
	0xEA,           //    nop
	0xEA,           //    nop
	0xBA,           //    tsx              ; SP -> X (W65C02 OPECODE)
	0xE8,           //    inx
	0x8E,0xF9,0xFF, //    stx  cpu_type    ; 0:W65C02 1:W65C816
	0xCB,           //    wai              ; wait CPU
// loop:
	0x80, 0xFE,     //    bra  loop
// 0xfff9
	0xFF,           //cpu_type:	db	$FF
	0xF6,0xFF,      //    FDB  NMIBRK		; NMI
	0xE7,0xFF,      //    FDB  RESET		; RESET
	0xF6,0xFF       //    FDB  IRQBRK		; IRQ/BRK
};

// Make IRQ pulse
static void make_irq(void)
{
	CLCSELECT = 1;		// CLC2 select
	G2POL = 1;			// /IRQ = 0 at rising CLK edge
	while(!CLC8OUT){}	// check until IRQ=1
	G2POL = 0;			// /IRQ = 1
	CLCSELECT = 7;		// CLC8 select
	G3POL = 1;			//
	G3POL = 0;			// reset CLC8OUT = 0; release CLC2 reset
}

// ************ timer0 setup ******************
// intervel about 10ms
//  f = 500kHz
// p = 1/f = 1/500KHz = 0.002ms
// 8 bit free running mode
// 256 * 0.002ms = 0.512ms period

// Prescaler Rate Select = 1:2   (b'0001)
//TMR0 Output Postscaler (Divider) Select  1:10 (b'1001)
// target period time = 0.512ms * 10 * 2 = 10.24ms
//
void setup_tomer0(void) {

//	T0CON0 = 0x89;	// timer enable, 8bit mode , 1:10 Postscaler 10ms
//	T0CON0 = 0x80;	// timer enable, 8bit mode , 1:1 Postscaler  1ms
	T0CON0 = 0x84;	// timer enable, 8bit mode , 1:5 Postscaler  5ms
//	T0CON0 = 0x81;	// timer enable, 8bit mode , 1:2 Postscaler  2ms
//	T0CON0 = 0x82;	// timer enable, 8bit mode , 1:2 Postscaler  3ms
//	T0CON0 = 0x83;	// timer enable, 8bit mode , 1:2 Postscaler  3ms
	T0CON1 = 0xa1;	// sorce clk:MFINTOSC (500 kHz), 1:2 Prescaler
	MFOEN = 1;
	TMR0H = 0xff;
	TMR0L = 0x00;
//	TMR0IF =0;	// Clear timer0 interrupt flag
//	TMR0IE = 1;	// Enable timer0 interrupt
}

void enable_interrupt(void) {

	U3RXIE = 1;		// Receiver interrupt enable
	TMR0IF =0;		// Clear timer0 interrupt flag
	TMR0IE = 1	;	// Enable timer0 interrupt
	// Global interrupt enable
	GIE = 1;
}
//
// define interrupt
//
// Never called, logically
void __interrupt(irq(default),base(8)) Default_ISR(){}

////////////// TIMER0 vector interrupt ////////////////////////////
//TIMER0 interrupt
/////////////////////////////////////////////////////////////////
void __interrupt(irq(TMR0),base(8)) TIMER0_ISR(){

//	if (!irq_flg) {
//		irq_flg = 1;
//		make_irq();
//	}
//	else irq_flg++;

	irq_flg++;

	TMR0IF =0; // Clear timer0 interrupt flag
}

////////////// UART3 Receive interrupt ////////////////////////////
// UART3 Rx interrupt
// PIR9 (bit0:U3RXIF bit1:U3TXIF)
/////////////////////////////////////////////////////////////////
void __interrupt(irq(U3RX),base(8)) URT3Rx_ISR(){

	unsigned char rx_data;

	rx_data = U3RXB;			// get rx data

	if ( rx_data == CTL_Q && fh.nmi_sw ) {
		nmi_sig = 1;
	}
	else if (rx_cnt < U3B_SIZE) {
		rx_buf[rx_wp] = rx_data;
		rx_wp = (rx_wp + 1) & (U3B_SIZE - 1);
		rx_cnt++;
	}
}

void wait_for_programmer()
{
    //
    // Give a chance to use PRC (RB6) and PRD (RB7) to PIC programer.
    //
    printf("\n\r");
    printf("wait for programmer ...\r\n");
    __delay_ms(1000);

    printf("\n\r");
}

// UART3 Transmit
void putch(char c) {
    while(!U3TXIF);			// Wait or Tx interrupt flag set
    U3TXB = c;				// Write data
}

// UART3 Recive ( PIC side )
int getch(void) {
	char c;

	while(!rx_cnt);
	U3RXIE = 0;					// disable Rx interruot
	c = rx_buf[rx_rp];
	rx_rp = (rx_rp + 1) & ( U3B_SIZE - 1);
	rx_cnt--;
	U3RXIE = 1;					// enable Rx interruot
    return c;               // Read data
}

// UART3 Recive( user side )
int u_getch(void) {
	char c;

	while(!rx_cnt) {
		if (nmi_sig) return(0);
	}
	U3RXIE = 0;					// disable Rx interruot
	c = rx_buf[rx_rp];
	rx_rp = (rx_rp + 1) & ( U3B_SIZE - 1);
	rx_cnt--;
	U3RXIE = 1;					// enable Rx interruot
    return c;               // Read data
}

unsigned int get_str(char *buf, uint8_t cnt) {
	unsigned int c, i;
	
	U3RXIE = 0;					// disable Rx interruot
	i = ( (unsigned int)cnt > rx_cnt ) ? rx_cnt : (unsigned int)cnt;
	c = i;
	while(i--) {
		*buf++ = rx_buf[rx_rp];
		rx_rp = (rx_rp + 1) & ( U3B_SIZE - 1);
		rx_cnt--;
	}
	U3RXIE = 1;					// enable Rx interruot
	return c;
}

void start_cpu(void) {

	bus_release_req();
	CLCSELECT = 0;			// CLC1 select
	G2POL = 1;				// /BE = 1 rising CLK edge
							// active CPU BUS

	LAT(W65_RESET) = 0;		// cpu reset
    __delay_ms(1);

	LAT(W65_RESET) = 1;		// cpu release reset

	CLCSELECT = 7;			// CLC8 select
	G3POL = 1;				//
	G3POL = 0;				// reset CLC8OUT = 0; release CLC2 reset
	irq_flg = 0;
}

uint8_t reset_cpu(void)
{
	int i;

	CLCSELECT = 0;			// CLC1 select
	G2POL = 0;				// /BE = 0 rising CLK edge
	bus_hold_req();

	// write cpu emulation mode operation program
	for (;;) {
		write_sram(rom_org, (uint8_t *)rom, sizeof(rom));
		read_sram(rom_org, &tmp_buf[0][0], sizeof(rom));

		if (memcmp(rom, &tmp_buf[0][0], sizeof(rom)) != 0) {
			bus_release_req();
			printf("Memory Write Error\r\n");
			while(1) {}
		}

		start_cpu();
		__delay_ms(10);

		CLCSELECT = 0;			// CLC1 select
		G2POL = 0;				// /BE = 0 rising CLK edge
								// CPU BUS Hi-z
		bus_hold_req();
		__delay_ms(1);
		read_sram(cpu_type, &tmp_buf[0][0], 1);
		switch (tmp_buf[0][0]) {
			case 0:
				return 0;		// CPU : W65C02
			case 1:
				return 1;		// CPU : W65C816
		}
		printf("Unknown CPU type(%02x)\r\n", tmp_buf[0][0]);
		printf("RESET CPU...\r\n");
		__delay_ms(300);
	}
}
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
